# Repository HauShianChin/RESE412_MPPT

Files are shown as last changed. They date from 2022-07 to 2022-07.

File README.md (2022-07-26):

# RESE412_MPPT

MPPT PCB design in Simulink and Altium Designer 

## Final RESE412 assignment 1.pdf

This report, I explored the sizing of a nanogrid and a microgrid, performing a topology analysis. The analysis compares a community of individual nanogrids, with the more traditional method of microgrid design. Individual household power systems operating independently, versus a collective microgrid approach will be discussed.

When both the individual nanogrid and microgrid topologies are designed and simulated, I observed the losses within each topology to ascertain the efficiency of the systems. This information, along with the financial cost of the system will allow me to make a recommendation to a community as to which topology will be more economically viable in the long term.

## RESE412 assignment 2 demand side management.pdf

In report, I will be building on the previous assignment's model to improve the microgrid system with control. Additionally, I will be implementing demand side management (DSM) using a single thermostatically controlled load (water heater) in each house using Simulink. I will revisit the stand-alone PV/battery system and see if I can reduce the capital cost of the solution.

The aim is to shift the water heater load to a time that better suits PV power production. With this shift in load, I should be able to reduce your battery storage and in theory reduce the capital cost of the microgrid solution (ignoring the cost of control infrastructure). Another constraint is that the water reaches “T High WH” at least once a day (T High WH can be found in the Simulink model, ideally its 60 degrees, However, set a little lower in a couple of the houses). This is to ensure bacteria doesn’t build up in the water heater of the Simulink model.

## MPPT assignment 3 412 final and proofread.pdf

A maximum power point tracker (MPPT) is a device that you will see regularly in household renewable energy systems. It manages the output of the solar panels, typically incorporating a battery management system, sometimes even coupled with an inverter. The MPPT dynamically alters the impedance seen by the photovoltaic (PV) panels. This is particularly advantageous in cloudy conditions or if the load is changing regularly. In this project, I will be designing and building an MPPT that will connect to two 10W polycrystalline panels. Students will test their MPPT against a system which does not have any control in order to determine the success of the MPPT controller.

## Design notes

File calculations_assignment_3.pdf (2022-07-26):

close all
clc

Freq = 30000;
Vpp = 17.4;
Po = 21.228;
R1 = 1;
R2 = 10;
R3 = 100;

Iout1 = sqrt(Po/R1)

Iout1 = 4.6074
Vout1 = Iout1*R1

Vout1 = 4.6074
Pa = Iout1*Vout1

Pa = 21.2280

Iout2 = sqrt(Po/R2)

Iout2 = 1.4570
Vout2 = Iout2*R2

Vout2 = 14.5698
Pb = Iout2*Vout2

Pb = 21.2280

Iout3 = sqrt(Po/R3)

Iout3 = 0.4607
Vout3 = Iout3*R3

Vout3 = 46.0739
Pc = Iout3*Vout3

Pc = 21.2280

DL1 = 0.2*Iout1*(Vout1/Vpp)

DL1 = 0.2440
DL2 = 0.2*Iout2*(Vout2/Vpp)

DL2 = 0.2440

DL3 = 0.2*Iout3*(Vout3/Vpp)

DL3 = 0.2440

L1 = abs((Vpp*(Vout1-Vpp))/(Freq*DL1*Vout1))

L1 = 0.0066
L2 = abs((Vpp*(Vout2-Vpp))/(Freq*DL2*Vout2))

L2 = 4.6174e-04
L3 = abs((Vpp*(Vout3-Vpp))/(Freq*DL3*Vout3))

L3 = 0.0015

D1 = Vout1/(Vout1+Vpp)

D1 = 0.2094
D2 = Vout2/(Vout2+Vpp)

D2 = 0.4557
D3 = Vout3/(Vout3+Vpp)

D3 = 0.7259

C1 = (Iout1*D1)/(30000*0.05*Vout1)

C1 = 1.3957e-04
C2 = (Iout2*D2)/(30000*0.05*Vout2)

C2 = 3.0382e-05
C3 = (Iout3*D3)/(30000*0.05*Vout3)

C3 = 4.8391e-06

%current sensor
VoMax = 5 %voltage going into the MCU

VoMax = 5
VoMin = VoMax/(2^10) %min voltage going into the MCU

VoMin = 0.0049
Iimin = 0 %min current

Iimin = 0

ViMax = 50*10^-3 %at least 10x bigger than Vos

ViMax = 0.0500
IiMax = 0.61*2 % maximum current measured

IiMax = 1.2200

Rshunt = ViMax/IiMax %shunt resistor

Rshunt = 0.0410
G = (VoMax - VoMin)/((IiMax - Iimin)*Rshunt) %gain calculations

G = 99.9023
RpositiveIn = 1000 %positive terminal resistor

RpositiveIn = 1000
RpositiveFed = RpositiveIn*G %positive feedback

RpositiveFed = 9.9902e+04

%G = R3/R2

RnegativeIn = RpositiveIn

RnegativeIn = 1000
RnegativeFed = RpositiveFed

RnegativeFed = 9.9902e+04

%voltage sensor
%G = R2/R1 = 1/5
%VoMax voltage going into the MCU %VoMin min voltage going into the MCU %Gain = Vo/Vi
GVoltage = 5/17.4

GVoltage = 0.2874
RVoltageIn = 10000 %ohms

RVoltageIn = 10000
RVoltageFed = GVoltage*RVoltageIn

RVoltageFed = 2.8736e+03

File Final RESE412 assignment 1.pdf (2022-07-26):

Author: Hau Shian Chin
Student ID: 300493343
Introduction

The purpose of this report is to explore the idea of placing a microgrid and nanogrid system to support a community in Hicks Bay. This nano- and microgrid system's specifications include an analysis of the local environment, total load curve, and size of the nano- and microgrid. Additionally, the system must be off-grid and must service 95% of its load. We will analyse the cost and efficiency of both systems as well as their advantages and disadvantages to make a viable recommendation about load use and demand side management for this community.

Village Load and Resources Assessment

Hicks bay was picked as the subject of village load as it has both sufficient sun exposure as well as high wind currents due to being close to the sea. Furthermore, the exact location at which data will be collected from will be the coordinate of -37.595915, 178.300842. This would mean that the sunlight data and the wind data will be extracted from this location. Although not every solar panel and wind turbine can fit into this coordinate, this can be negligible when calculating the power provided to the village.

Topology

As the sun rises from the east and sets in the west, we would expect the location to not receive much sunlight before noon as it’s stationed next to 2 hills [1]. Additionally, this may result in a potential shade for the solar panels leading to less power output. This can be observed in Figure 1. However, peak sunlight hours calculated from NIWA may prove these 2 variables to be negligible. Furthermore, there may be some anomalies regarding how wind would be harvested. This may be negligible as well since both wind frequency and wind speed will be considered when calculating the harvestable wind in that region.

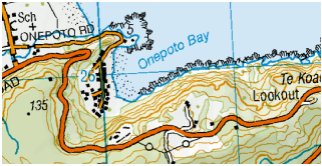
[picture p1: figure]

Figure 1: topology of the coordinate.

Resource assessment

Solar analysis

On NIWA the location was exposed to 3.107 hours of peak sunlight hours during the winter month (June) on average [2]. As winter has the least amount of sunlight hours of all seasons, it will tell us what is the least amount of energy we can harvest from the sun. Additionally, this will provide us with the sufficient data to model an energy supply from solar power. As shown in Figure 2, peak sunlight hours was calculated from the total sunlight hour, summed up to provide a total number of hours providing 1kW. This makes sense as the sun would peak at noon but set in the evening.

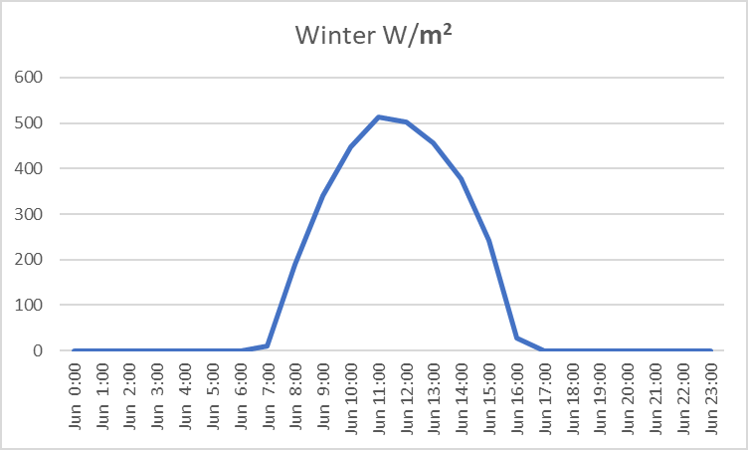
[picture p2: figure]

Figure 2: Mean sunlight hours during winter

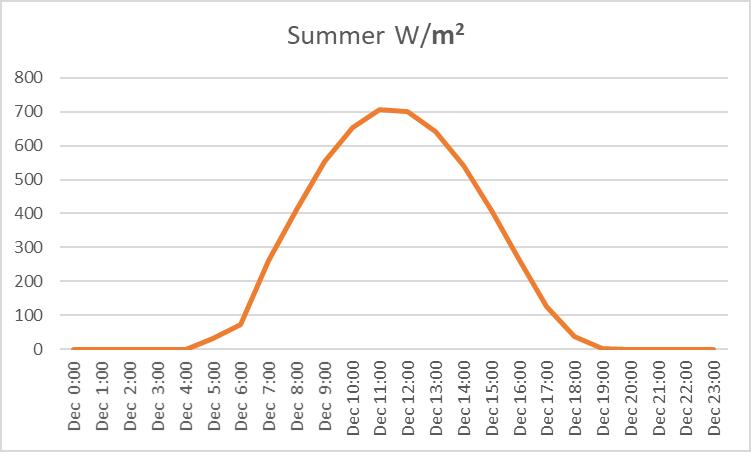
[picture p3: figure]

Figure 2: Mean sunlight hours during summer.

The Figure above is the sunlight hours during the summer month (December). This resulted in a peak sunlight hour of 5.417 hours during summer. Moreover, this may be considered as a constraint to determine the inverter power output when exporting power to the grid in the future. During the summer there may be network congestion due to other inverters exporting at the same time. However, this may be able to address future load growths during summer.

Wind analysis

Using the meteorology data of NIWA, we have compiled the first week of June's wind speed to determine the average effective wind hours [2]. The effective wind hours that are available in a single day is calculated by considering the wind speed, wind frequency at that speed and the curvature of the turbines to determine an energy output (Figure 3). This resulted in an effective wind hour of 4.475 hours a day.

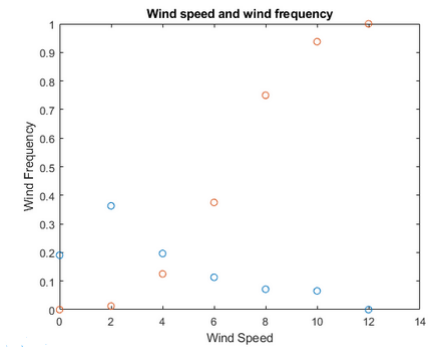
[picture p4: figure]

Figure 3: wind speed and wind frequency (e.g. 0.4 = 40% of the time) at that speed.

Load analysis

Nanogrid load analysis

To determine the load, a nanogrid will be considered as a single house’s load whereas a microgrid will be the load sum of 4 houses. Both winter and summer loads will be explored to provide a feasible comparison between the 2 seasons. Additionally, both loads and instantaneous power will be observed.

To calculate the energy expenditure of a single nanogrid. The current draw of each unit will be calculated and multiplied by the national rated voltage (240 V). These sets of discrete values will be sampled for every minute of the day to provide a set of instantaneous power. Moreover, this dataset requires integrating to provide the load curve and thus the energy expenditure of the household. Both summer and winter load curves of all the nanogrids can be seen on Figure 4. Green being house 8, blue being house 3, black being house 9 and orange being house 4. The load will be serviced using AC current as a result an inverter is needed to support the nano-microgrid.

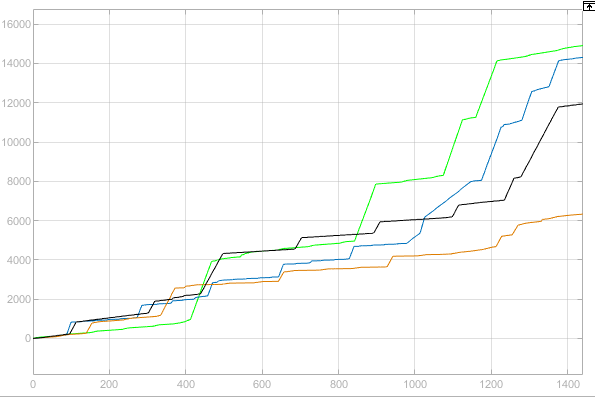
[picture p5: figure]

Summer load

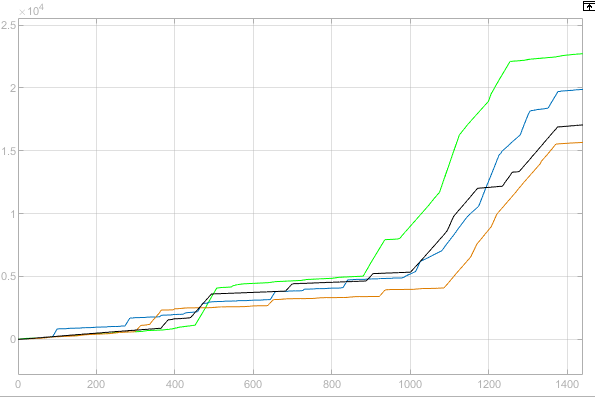
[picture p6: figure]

Winter load
Figure 4: Daily seasonal load curves of the nanogrids

The nanogrids’ energy expenditure for both summer and winter can be shown in Table 1, since the system has a minimum requirement of 95% of its load serviced, 100% of the energy expenditure will be considered as the excess that may be needed. These energy expenditures below will provide the sufficient energy required for component selection. It is expected that winter has higher energy demand than summer. As a result, all components selected for the nanogrid will be used to service its winter load. Additionally, the nanogrids energy expenditure can be totalled up to provide the energy expenditure for the microgrid. Instantaneous power determines the peak power drawn at any given time from the grid. This can be observed in Figure 5.1-4 where both summer and winter instantaneous power can be observed.

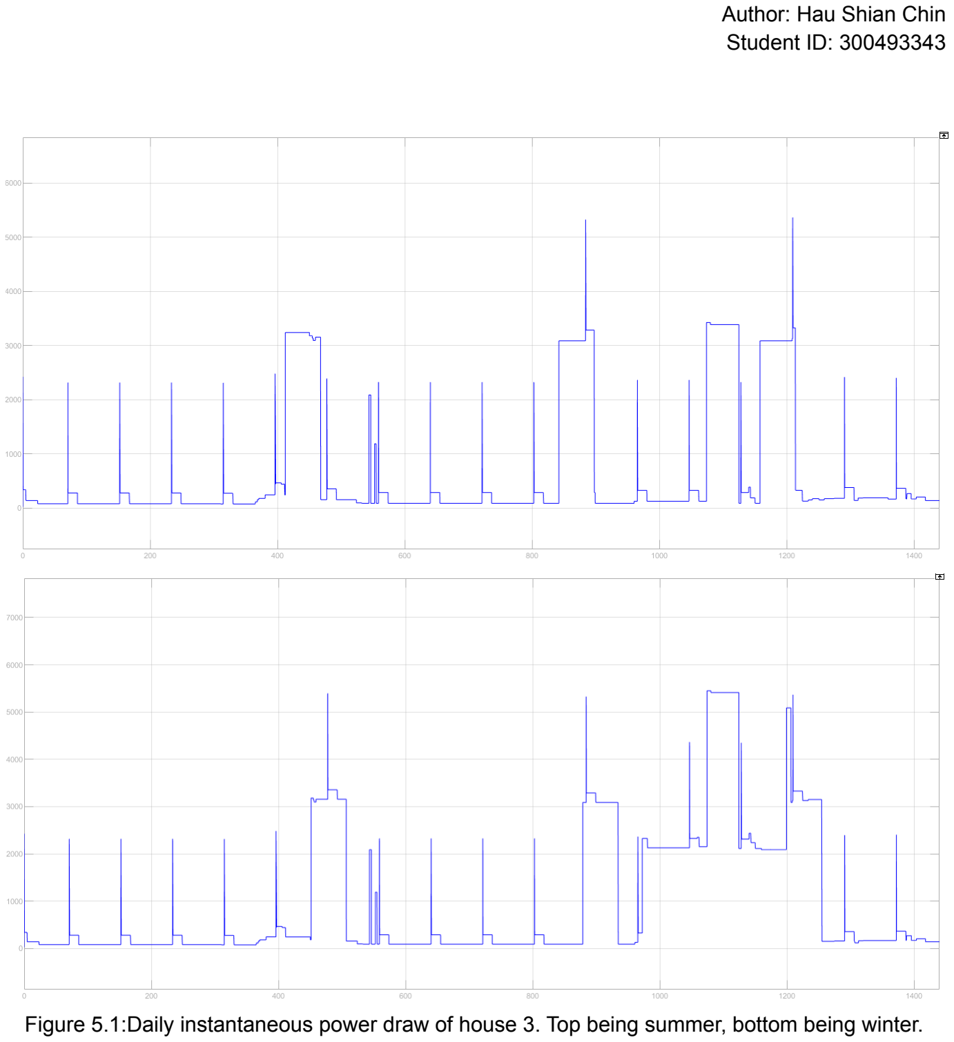
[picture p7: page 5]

Figure 5.1:Daily instantaneous power draw of house 3. Top being summer, bottom being winter.

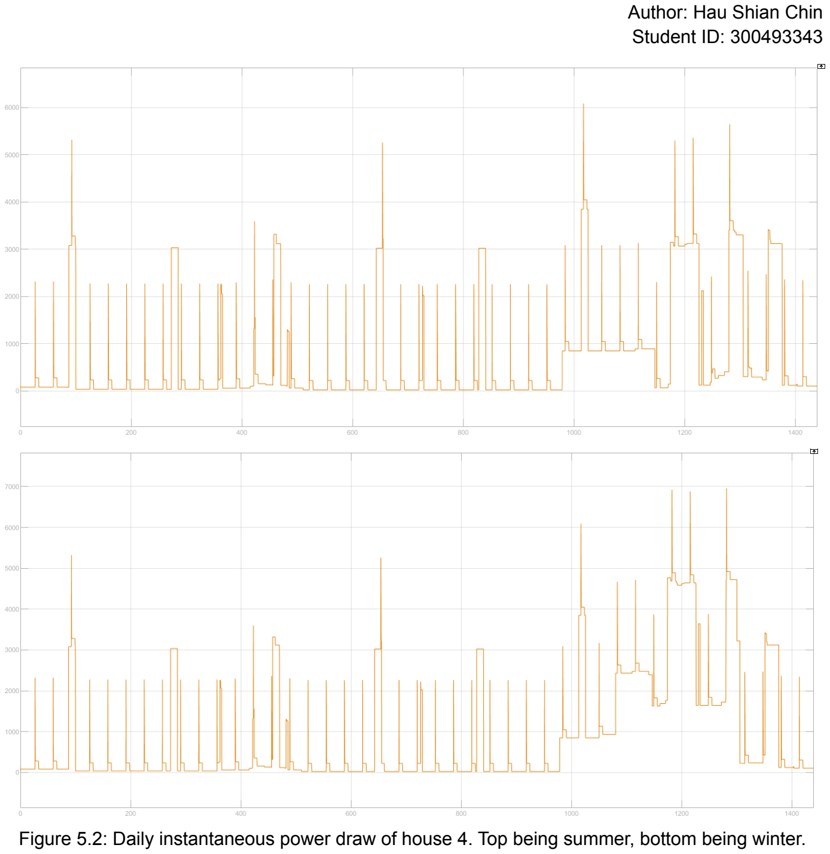
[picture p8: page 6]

Figure 5.2: Daily instantaneous power draw of house 4. Top being summer, bottom being winter.

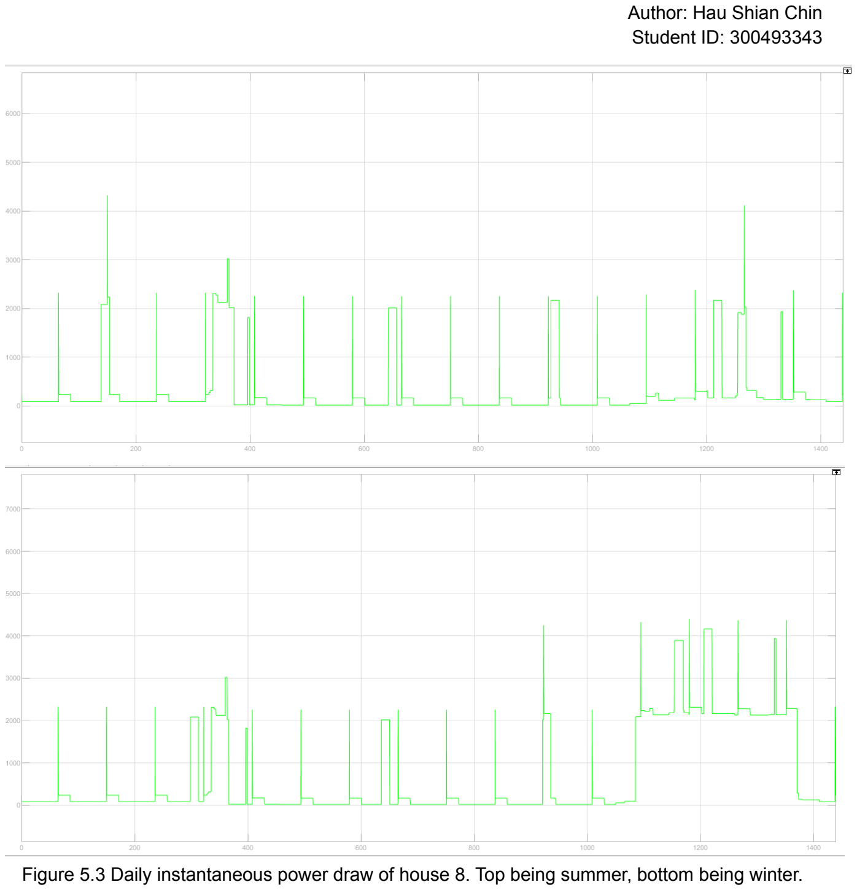
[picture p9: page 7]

Figure 5.3 Daily instantaneous power draw of house 8. Top being summer, bottom being winter.

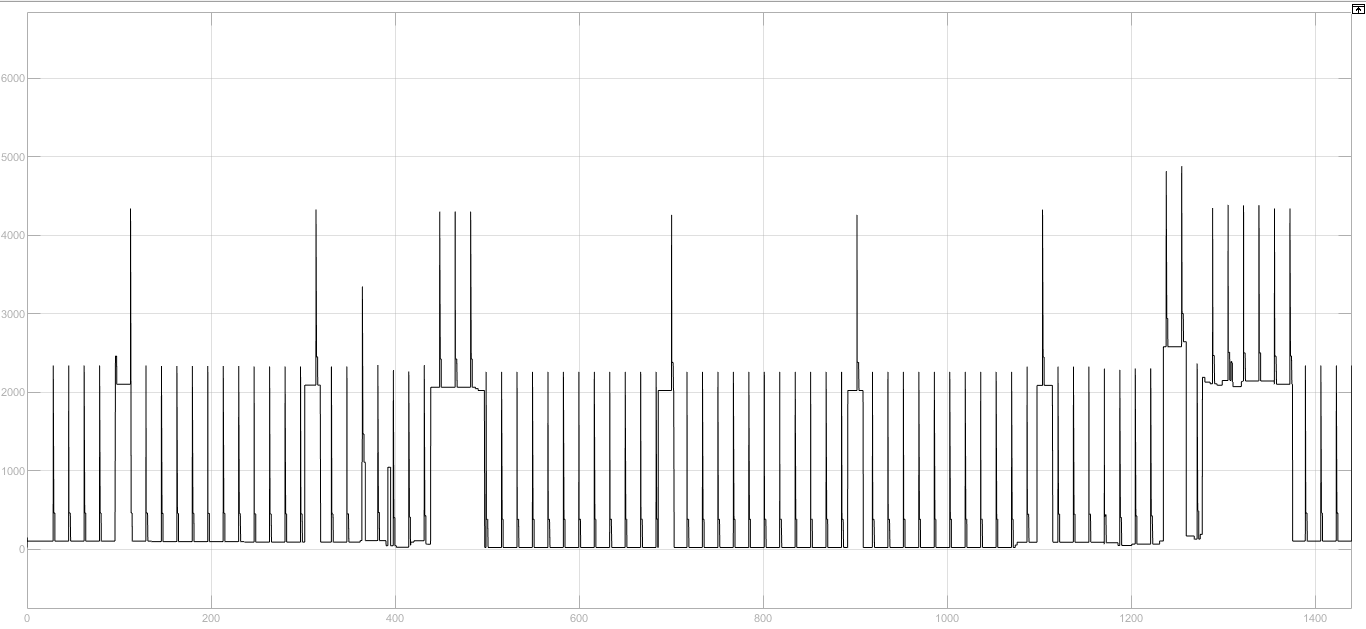
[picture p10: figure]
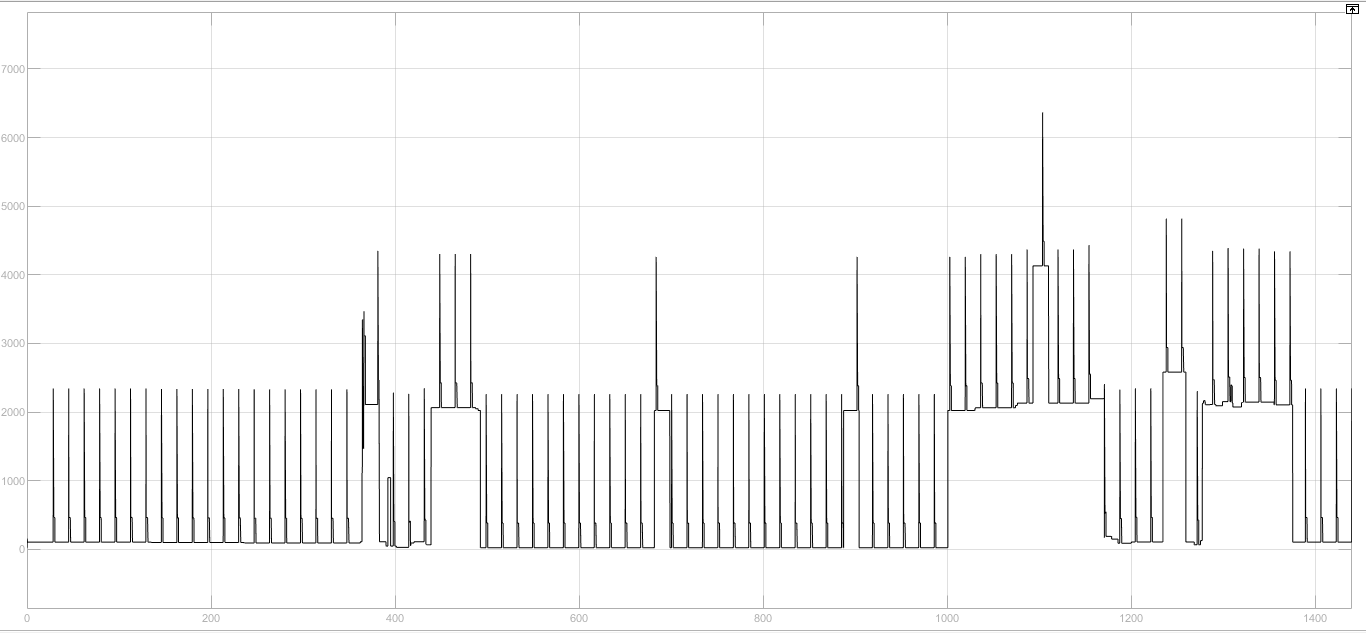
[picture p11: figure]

Figure 5.4: instantaneous power draw of house 9.Top being summer, bottom being winter.

These are the instantaneous power draw of each nanogrid. As shown in Figures 5.1-4, it is a recurring trait that all households tend to use more power during the evening. This makes sense as most people spend recreational time during the evening. E.g. watching TV, cooking. Unlike the daily energy expenditure the instantaneous power of each nanogrid is expected to be the same as most people would have the same routine year round.

Nanogrid | Summer daily energy expenditure | Peak instantaneous summer load | Winter daily energy expenditure | Peak instantaneous winter load
House 3 | 14.3 kWh | 6 kW | 19.8 kWh | 7 kW
House 4 | 6.4 kWh | 4.3 kW | 16.0 kWh | 4.5 kW
House 8 | 15.0 kWh | 5.4 kW | 23.2 kWh | 5.5 kW
House 9 | 12.0 kWh | 5 kW | 17.7 kWh | 5.4 kW
Table 1: seasonal energy expenditure of all nanogrids.

Microgrid load analysis

As shown in Figure 6.1, the summer microgrid daily energy expenditure is approximately 48 kWh. Whereas, the winter microgrid daily energy expenditure is approximately 77 kWh. As a result, winter energy expenditure will be considered when considering the capacity of battery, capacity of inverter, quantity of PVs and wind turbines selected.

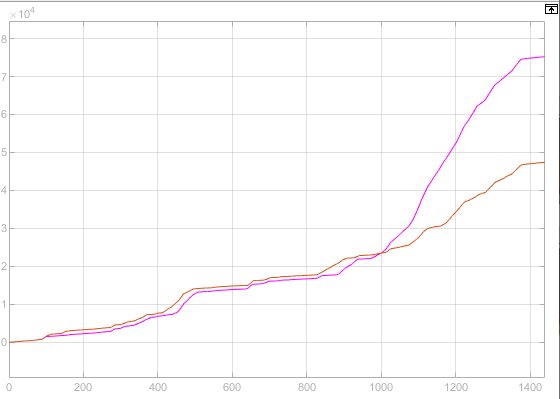
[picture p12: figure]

Figure 6.1: Microgrid daily energy expenditure for summer and winter. Purple = Winter, Orange = Summer

All wind turbines connected to the battery must first be converted to DC to allow the battery to charge. However, the PVs would not need any conversion to allow the battery to charge as its generated via DC current.

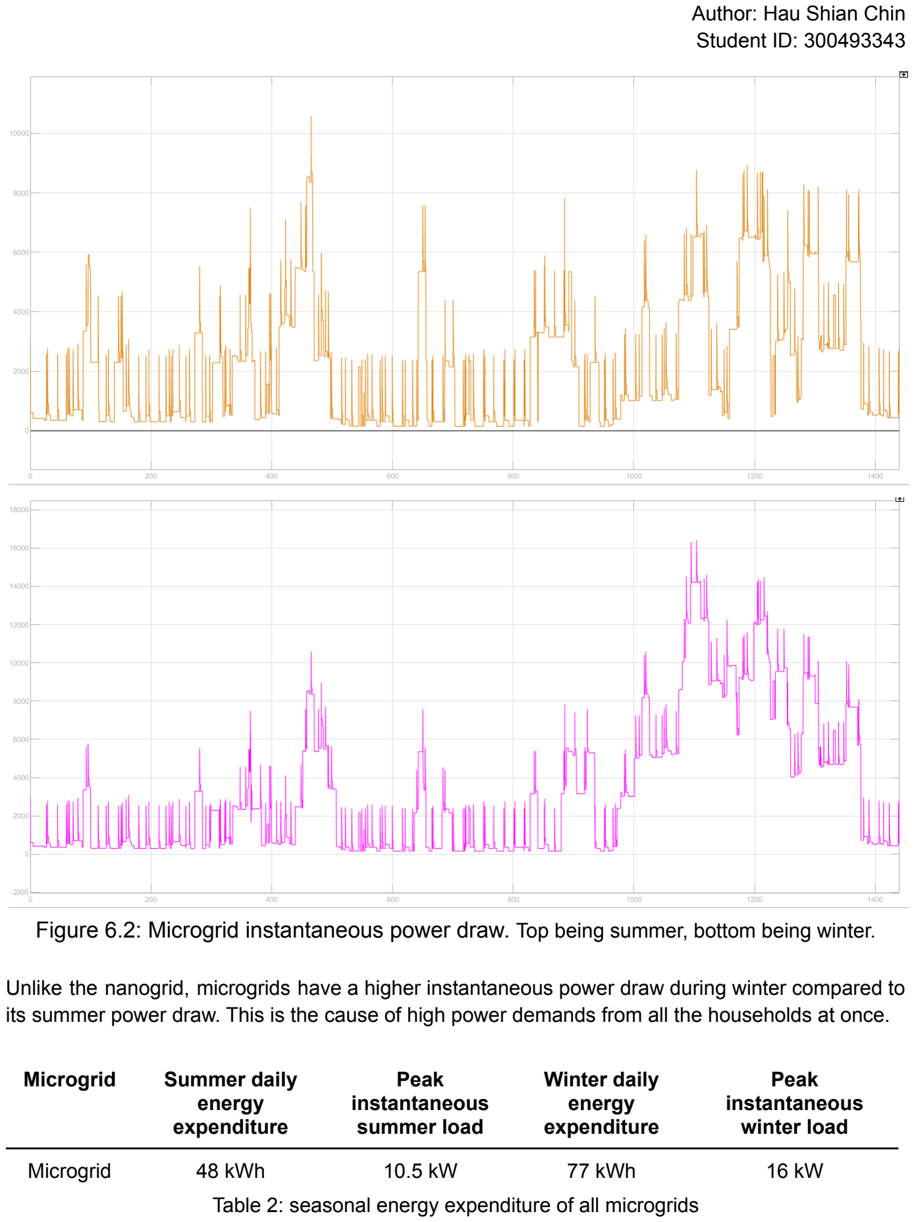
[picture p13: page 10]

Figure 6.2: Microgrid instantaneous power draw. Top being summer, bottom being winter.

Unlike the nanogrid, microgrids have a higher instantaneous power draw during winter compared to its summer power draw. This is the cause of high power demands from all the households at once.

Microgrid | Summer daily energy expenditure | Peak instantaneous summer load | Winter daily energy expenditure | Peak instantaneous winter load
Microgrid | 48 kWh | 10.5 kW | 77 kWh | 16 kW
Table 2: seasonal energy expenditure of all microgrids

Component Selection

component | Capital cost (per unit) | O&M cost | Replacement time
PV | $750 /kW | $1 /280W /year | 25 year
Wind | $1460 /kW | $146 / 500W /year | 20 year
Battery | $110 /kW | $11 /kWh /year | 10 year
Inverter | $364 /kW | 0.0026 /kW /year | 10 year
Table 3: component cost of the project in USD

PVs, wind turbines and battery selection will be based on the winter energy expenditure as it has a higher load curve compared to summer’s energy expenditure. Components selected from Table 3 must accommodate for the loads in Table 1. In addition, this allows us to compare the financial benefits of microgrid and nanogrid when their loads are high. For a self-sustaining community, it is more important to have an energy surplus than a deficit since to accommodate for later use. As a result, both solar panels and wind turbines calculated in Table 4 must be rounded up to ensure an energy surplus. Additionally, all calculations below will be done in USD before converting to NZD.

Method of energy harvesting

The method of energy harvesting will determine how the nanogrid will be powered. The method of harvesting would be PVs (solar energy) and/or wind turbines. To determine how many PVs and turbines required, the daily energy expenditure will be divided by the energy output of the system. Additionally, the initial cost will consider the required quantity of PVs and wind turbines, the rated power output and the initial cost of the equipment. Finally, the operation and maintenance cost (O&M cost) will consider the quantity of equipment and the annual operation and maintenance cost.

required quantity of equipment = Daily energy expenditure ፥ (power output * functional ℎours) initial cost = power output of tℎe equipment * required quantity of equipment * cost of equipment OM cost = O&M cost per year for tℎe equipment * required quantity of equipment

Nanogrid | Daily energy expenditure | Required PVs (280 W) | Initial cost | O&M cost per year
House 3 | 19.8 kWh | 23 | $4830 | $23
House 4 | 16.0 kWh | 19 | $3990 | $19
House 8 | 23.2 kWh | 27 | $5670 | $27
House 9 | 17.7 kWh | 21 | $4410 | $21

Nanogrid | Daily energy expenditure | Required wind turbines (500 W) | Initial cost | O&M cost per year
House 3 | 19.8 kWh | 9 | $6570 | $1314
House 4 | 16.0 kWh | 8 | $5840 | $1168
House 8 | 23.2 kWh | 11 | $8030 | $1606
House 9 | 17.7 kWh | 8 | $5840 | $1168
Table 4: PVs and wind turbines required quantity and costs for nanogrids

As shown in Table 4, although solar panels may be more cost effective in general. Solar panels are made redundant if there’s low sun exposure as well as only effective for 3.107 hours of the day. However, this can be made negligible by allowing a greater battery capacity. Wind turbines have a high upkeep cost and initial cost as a result, will not be considered when sizing the nanogrid. Additionally, it may require a voltage rectifier to charge the battery as the battery charges in DC.

Battery management system

Battery management system must be able to supply enough energy to the nanogrids until the next morning. Additionally, the battery management system must be doubled to accommodate for the days when power can not be generated as well as supporting the nanogrid during down time. This will lower the chances that the battery will go below 50% on cloudiest days during winter which may result in battery damage.

Nanogrid | Daily energy expenditure | Battery capacity | Initial cost | O&M cost per year | After replacement cost
House 3 | 19.8 kWh | 39.6 kWh | $4356 | $435.60 | $8712
House 4 | 16.0 kWh | 32 kWh | $3520 | $352 | $7040
House 8 | 23.2 kWh | 46.4 kWh | $5104 | $510.4 | $10208
House 9 | 17.7 kWh | 35.4 kWh | $3894 | $389.4 | $7788
Table 5: Battery capacity and costs for nanogrids

The cost stated in Table 5 was doubled to compensate for the replacement cost. This was the result of the battery lifespan being 10 years where this project span is 20 years.

Inverters

The purpose of the inverter is to provide sufficient AC power to the nanogrid. This AC power must accommodate for the peak instantaneous load as that’s the maximum load required to accommodate at any time. There must be extra capacity to prevent overloading. To accommodate for this safety measure, the inverter capacity will be 50% greater than the peak instantaneous power of the nanogrid when determining inverter capacity.

Nanogrid | Peak instantaneous power in winter (kW) | Inverter capacity | Initial cost | OM cost per year | After replacement cost
House 3 | 7 kW | 10.5 kW | $3,822 | $0.03 | $7,644
House 4 | 4.5 kW | 6.75 kW | $2,457 | $0.02 | $4,914
House 8 | 5.5 kW | 8.25 kW | $3,003 | $0.03 | $6,006
House 9 | 5.4 kW | 8.1 kW | $2,948.4 | $0.03 | $5,897
Table 6: Inverter capacity and costs for nanogrids

The cost stated in Table 6 was doubled to compensate for the replacement cost. This was the result of the inverter lifespan being 10 years where this project span is 20 years. There were some abnormalities since house 9 has a greater peak instantaneous power compared to house 4, this was a result of high power draw at a given time.

Nanogrid costs in NZD

Nanogrid | PVs cost + annual O&M cost | Wind turbines cost + annual O&M cost | Inverter cost + annual O&M cost | Battery cost + annual O&M cost
House 3 | $6,955 + $33 | $9,461 + $1,892 | $11,007 + $0.04 | $12,545 + $627.26
House 4 | $5,746 + $27 | $8,410 + $1,682 | $7,076 + $0.03 | $10,138 + $507
House 8 | $8,165 + $39 | $11,563 + $2,313 | $8,649 + $0.04 | $14,700 + $734.98
House 9 | $6,350 + $30 | $8,410 + $1,682 | $8,492 + $0.04 | $11,215 + $560.74
Table 7: Total cost of the components for nanogrids

Table 7 summarises the cost of each component from Tables 4 to 6 with its annual operating and maintenance cost in NZD (appended with an + sign). This will provide a better insight to the total cost of the nanogrid projects as the system is hosted in the NZ setting. As the initial and upkeep cost of wind is less cost effective than solar, wind power will not be used when sizing a nanogrid. However, it will be included in the economic analysis to provide an economical comparison.

Microgrid costs

All the calculations in Table 8 were done in USD to prevent miscalculations. As the energy expenditure of each nanogrid totals up to provide the microgrid’s energy expenditure, the total cost of PVs/wind and battery in the nanogrids can be totalled up to provide its respective cost for the microgrid.
Microgrid | Daily energy expenditure | Required PVs (280 W) | Initial cost | OM cost per year
Microgrid | 77 kWh | 90 | $18900 | $90
Microgrid | Daily energy expenditure | Required wind turbines (500 W) | Initial cost | OM cost per year
Microgrid | 77 kWh | 36 | $26,280 | $5256
Microgrid | Daily energy expenditure | Required battery capacity | Initial cost | OM cost per year | After replacement cost
Microgrid | 77 kWh | 153.4 kWh | $16,874 | $1,687 | $33,748
Microgrid | Peak instantaneous power in winter (kW) | Inverter capacity | Initial cost | OM cost per year | After replacement cost
Microgrid | 16 kW | 24 kW | $8,736 | $0.06 | $17,472
Table 8: Inverter capacity and costs for nanogrids

As shown in Table 2. The peak instantaneous power drawn for the microgrid is 16 kW. This allows the microgrid to cut costs for the inverter as it only requires 24 kW instead of the sum of the peak power drawn for the nanogrids.

Microgrid cost in NZD

Microgrid | PVs cost + annual O&M cost | Wind turbines cost + annual O&M cost | Inverter cost + annual O&M cost | Battery cost + annual O&M cost
Microgrid | $27,216 + $130 | $37,843 + $7,569 | $25,159.68 + $0.09 | $48,597 + $2,429.86
Table 9: Total cost of the components for nanogrids

Table 9 summarises the cost of the components in Table 8 along with its annual operating and maintenance cost in NZD (appended with an + sign). This will provide a better insight to the total cost of the microgrid project. As the initial and upkeep cost of wind is less cost effective than solar, wind power will not be used when sizing a microgrid. However, it will be included in the economic analysis to provide an economical comparison.

Nanogrid technical considerations

Technical considerations include making sure that all the inductive and capacitive loads have phase correction units so that it may not cause disturbance elsewhere in the house. In the nanogrid, software may be needed to optimise power usage, such as allowing charging to happen simultaneously with discharging. During the summer, when the PVs are more efficient, bus load may be a concern. It may be recommended that PVs operate during some of the daytime hours to avoid bus overload. All buses must be low resistance to prevent voltage curtailing.

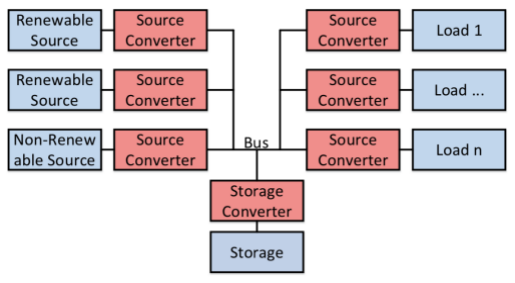
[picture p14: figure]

Figure 7: example of a bus load

Microgrid technical considerations

Microgrids will likely use more wiring and buses than the nanogrids. Additionally, the microgrid may need some protective brakes/relays to prevent any faults from affecting other houses. Furthermore, there may be an increase in bus load as the microgrid connects to each household thus, additional phase protection may need to be implemented to accommodate load growth. Single phase lines will be required to deliver power to each of the houses.

Microgrids will also require a more complex software to optimise the load demands of each household. This software may be used inside the central processing unit of the microgrid to accommodate for the load curves and bus load of the system. Furthermore, there will be additional costs associated with this software.

Nanogrid PVs system simulation model

To provide a realistic simulation of the nanogrids in simulink a week of tilted solar irradiance was picked. The week of the winter solstice was picked to provide the sunlight hours 21st of June 2021 to 27th of June 2021 [2]. This week was to showcase how the nanogrids would perform in the least optimal winter conditions. This week has a mean of 4.031 peak hours a week. As shown in the Figures below the nanogrids required to draw some energy out of the energy reserve to sustain the house. This was a result of a lack of solar irradiance during the day. The orange line represents the energy usage of the battery management system and the blue line represents the instantaneous power throughout the day. It can be observed in Figures 8.1-4 that all nanogrids have shown to be able to sustain the load demand of its household with a slight drop below 50% battery capacity. We can conclude that the components selected for the nanogrids are viable.

House 3

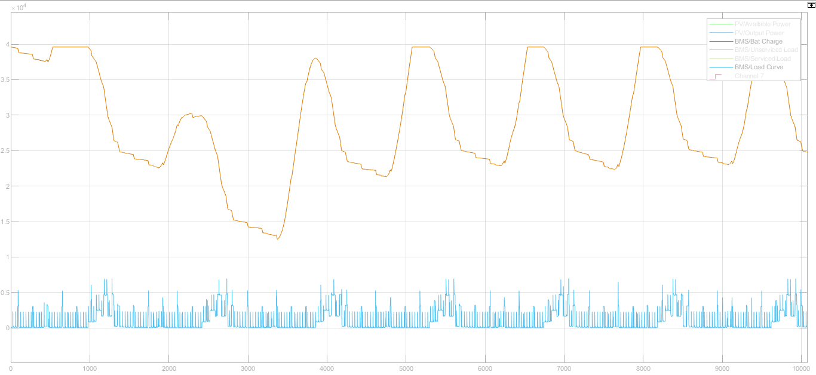
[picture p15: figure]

PVs capacity | Battery capacity | Inverter capacity
6.44 kW | 39.6 kWh | 10.5 kWh
Figure 8.1: house 3 battery management system and instantaneous power demand

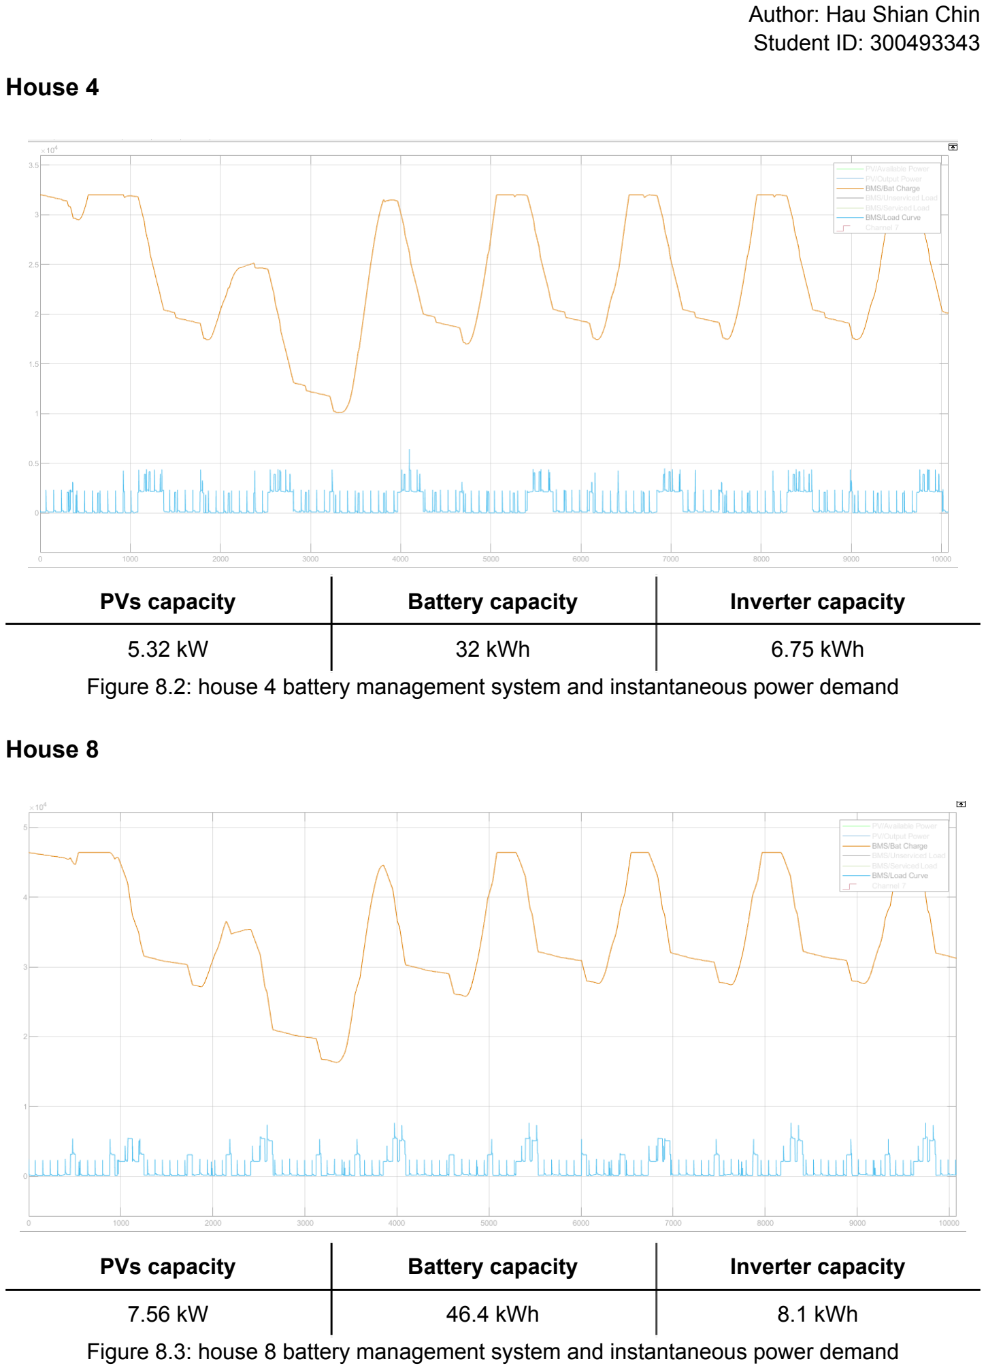
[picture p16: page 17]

House 4

PVs capacity | Battery capacity | Inverter capacity
5.32 kW | 32 kWh | 6.75 kWh
Figure 8.2: house 4 battery management system and instantaneous power demand

House 8

PVs capacity | Battery capacity | Inverter capacity
7.56 kW | 46.4 kWh | 8.1 kWh
Figure 8.3: house 8 battery management system and instantaneous power demand

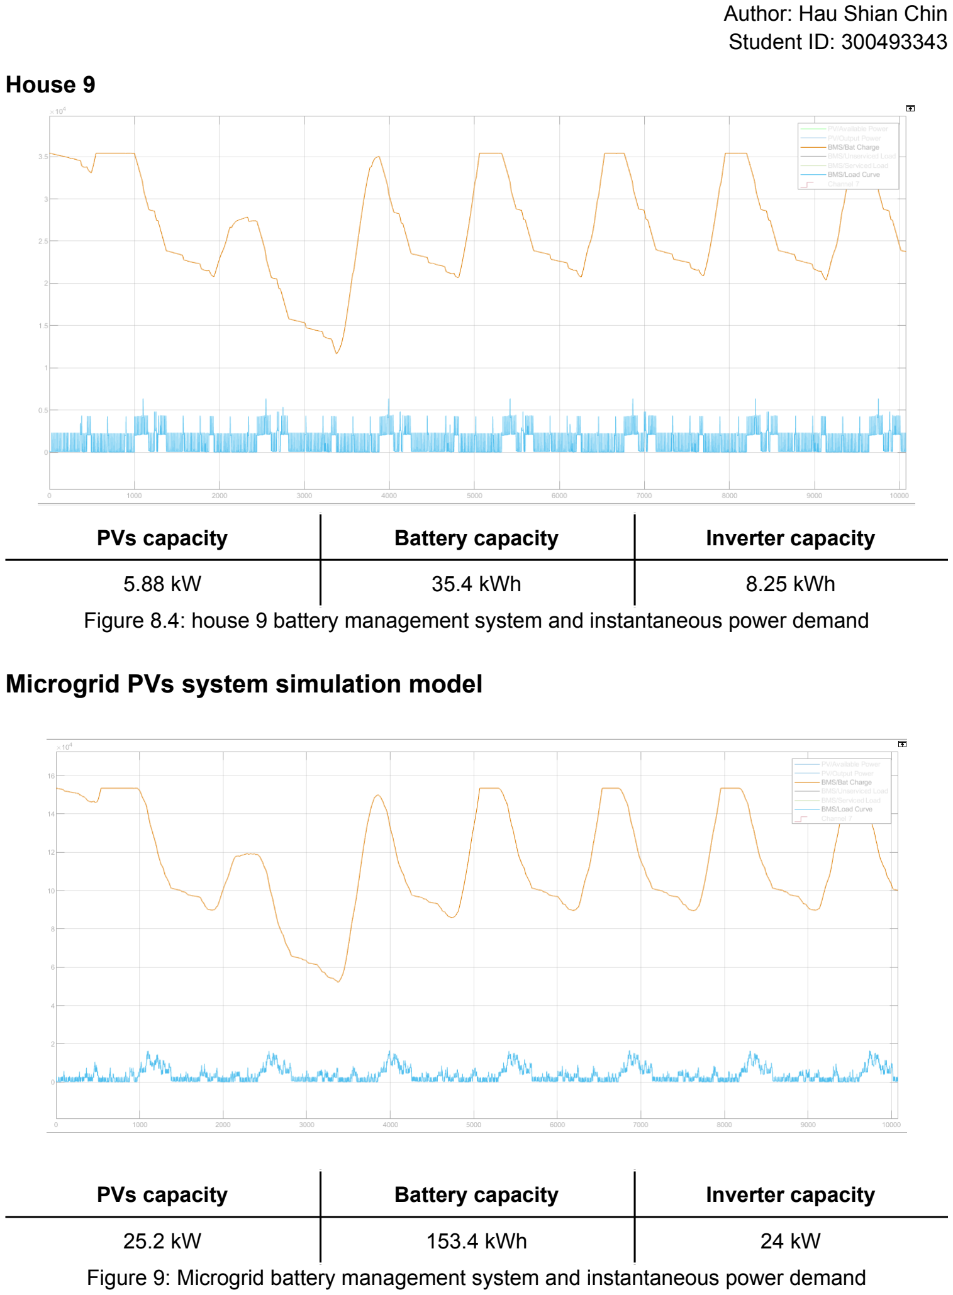
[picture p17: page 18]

House 9

PVs capacity | Battery capacity | Inverter capacity
5.88 kW | 35.4 kWh | 8.25 kWh
Figure 8.4: house 9 battery management system and instantaneous power demand

Microgrid PVs system simulation model

PVs capacity | Battery capacity | Inverter capacity
25.2 kW | 153.4 kWh | 24 kW
Figure 9: Microgrid battery management system and instantaneous power demand

The same process of exposing the microgrid with the same sunlight hours as the nanogrid provided a fair comparison of how each system would fare in the same weather conditions. In Figure 9, the orange line represents the energy usage of the battery and the blue line represents the instantaneous power drawn for the system. It can be observed that the battery was enough to sustain the load demand of the microgrid. As a result we conclude that the component selected would make this microgrid viable.

Nanogrid economical analysis

To determine the economical feasibility of the nanogrids, Simple Payback, Net Present Value and Levelised Cost of Energy (LCOE) will be used as a metric of comparison. The grid price per kwh ($0.29 NZD to $0.2 USD) will also be considered as well as rebates to determine the Simple Payback. Additionally, the PVs based system will only consider the cost of the battery, inverter and PVs whereas the wind based system will only consider the cost of the battery, inverter and PVs. The calculations will all be conducted in USD before converting to NZD to prevent miscalculations. NZD to USD conversion is assumed at $1.44 NZD to $1 USD.

Net Annual energy saving ($/year) = [AOE (kWℎ/year) * Price ($/kWℎ)] − O&M ($/year)

Nanogrid | Annual energy output (AOE) | PVs Net Annual Energy Savings (NZD) | Wind Net Annual Energy Savings (NZD)
House 3 | 7227 kWh | $ 1,420.95 | -$ 438.09
House 4 | 5840 kWh | $ 1,147.65 | -$ 506.91
House 8 | 8468 kWh | $ 1,664.90 | -$ 608.86
House 9 | 6460.5 kWh | $ 1,269.62 | -$ 382.06
Table 10: Annual energy output and Net Annual Energy Savings of PVs and wind nanogrids

As each nanogrid will not be using all its produced power throughout the year. The annual energy output (AOE) can be considered using the energy production during winter multiplied by the number of days in the year. As observed in Table 10 the Net Annual Energy Savings is higher for PVs.

Simple Paybacks

To calculate the Simple Paybacks (years) the total installed cost is calculated by summing the cost of the PVs/wind turbines, battery cost and inverter cost. This payback will provide an insight as to when the cost of the project would break even. As observed in Table 11, PVs can break even during the span of the project but not wind turbines.
Paybacks (year) =

installed cost($) −Rebates($) Net Annual Energy Savings ($/year)
Nanogrid | PVs Simple Payback (years) | Wind turbines Simple Payback (years)
House 3 | 20.1 | 70.8
House 4 | 18.3 | 46.6
House 8 | 17.7 | 54.1
House 9 | 18.9 | 68.4
Table 11: Simple Payback for PVs and wind nanogrids

Discounted Net Annual Savings

Using Figure 10, we select a discount rate of 2% as well as consider the project span of 20 years. This provided a PVAF of 16.35. This can be used to calculate the Discounted Net Annual Savings in the Table below. The Net Present Value will consider all costs and savings for the lifetime of the project. Furthermore, the Net Present Value (NPV) can be calculated by subtracting the Discounted Net Annual Savings from the Initial Cost and the Rebates. Rebates are used as part of the initial cost as the government issues out financial incentives for the construction of nanogrids ($1389 USD).

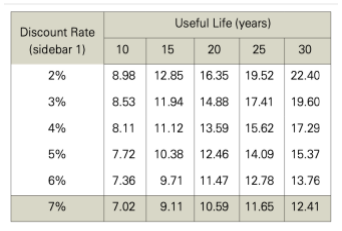
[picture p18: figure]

Figure 10: PVAF

Discounted Net Annual Savings ($) = Net Annual Energy Savings ($/year) * PVAF
Net Present Value (NPV) ($) = Discounted Net Annual Savings ($) − (installed cost($) − Rebates($))
Nanogrid | PVs Discounted Net Annual Savings (NZD) | Wind turbines Discounted Net Annual Savings (NZD) | PVs Net Present Value (NPV) (NZD) | Wind Net Present Value (NPV) (NZD)
House 3 | $ 23,232.57 | -$7,162.73 | -$5,275.11 | -$38,176.01
House 4 | $ 18,764.15 | -$8,287.91 | -$2,209.45 | -$31,911.11
House 8 | $ 27,221.07 | -$9,954.91 | -$2,291.73 | -$42,866.11
House 9 | $ 20,758.25 | -$6,246.72 | -$3,298.10 | -$32,362.27
Table 12: Discounted Net Annual Savings and Net Present Value of PVs and wind turbines for nanogrids

As observed in Table 12 all the NPVs for all nanogrids are negative, the nanogrid project will most likely lose money. As a result, this system is not economically viable. However, if a system must be built, the most economically viable ones would be the PVs as it has the highest NPVs values, specifically house 4 as it has the highest Discounted Net Annual Savings and NPV.

Levelised Cost of Energy

The Levelised Cost of Energy (LCOE) represents the discounted price that the system provides to breakeven over the project lifespan [3]. The nanogrids would be economically feasible if the LCOE is less than the grid price per kWh since it would be more cost effective to use the generated electricity than import power from the grid.

LCOE ($/kWℎ) =

Initial cost ($) + O&M ($/year) * PVAF Annual Energy Output (kWℎ/year) * PVAF

Nanogrid | PVs LCOE (NZD) | Wind turbines LCOE (NZD)
House 3 | $ 0.33 | $ 0.60
House 4 | $ 0.30 | $ 0.62
House 8 | $ 0.30 | $ 0.60
House 9 | $ 0.32 | $ 0.59
Table 13: LCOE of PVs / Wind nanogrids

As shown on the Table above, the LCOE is more than the price per kWh ($0.29) as a result not economically viable. However, there can be additional benefits such as being robust against outages. Outages can happen when there’s a sudden power demand in a more densely populated area and the grid will redirect power to accommodate the demand. Furthermore, the LCOE of the PVs system can be lowered there’s an increase in energy expenditure. This may indicate that an internal load growth may decrease the Levelised Cost of Energy.

Microgrid economical analysis

Using the same formulas and principles conducted on the nanogrids. We can obtain the Net Annual Energy Savings, Simple Paybacks, Net Present Value and Levelised Cost of Energy for the microgrid. These figures will help determine whether a microgrid project is economically viable.

Microgrid | Annual energy output (AOE) | PVs Net Annual Energy Savings (NZD) | Wind turbines Net Annual Energy Savings (NZD)
Microgrid | 28105 kWh | $ 5,590.90 | -$ 1,848.14
Table 14: Annual energy output and Net Annual Energy Savings of PVs and wind microgrid
Microgrid | PVs Simple Payback (years) | Wind Simple Payback (years)
Microgrid | 17.7 | 59.3
Table 15: Simple Payback for PVs and wind microgrid

Microgrid | PVs Discounted Net Annual Savings (NZD) | Wind Discounted Net Annual Savings (NZD) | PVs Net Present Value (NPV) (NZD) | Wind Net Present Value (NPV) (NZD)
Microgrid | $ 91,411.28 | -$ 30,217.02 | -$ 7,561.52 | -$ 139,817.02
Table 16: Discounted Net Annual Savings and Net Present Value of PVs and wind turbines for microgrid
Microgrid | PVs LCOE (NZD) | Wind turbines LCOE (NZD)
Microgrid | $ 0.31 | $ 0.59
Table 17: LCOE of PVs / Wind nanogrids for microgrid

In terms of NPV, Net Annual Energy Savings and Discounted Net Annual Savings, it has shown to be a similar value to the sum of the nanogrids as observed in Tables 14-17. However, the Simple Payback and LCOE indicates that the microgrid is slightly more economically viable than the nanogrid. This was a result of the lower cost spent on the inverter.

Conclusion and Recommendations

The location for this project may be improved to Whakatane as it’s a sunnier location. This would result in higher peak sunlight hours and require less PVs to support the microgrid. This would result in an overall lower cost to the project and would increase the Discounted Net Annual Savings of the project and decrease the LCOE. Additionally, an improvement in PV technology would also make microgrids more economically viable in the future. Furthemore, an Maximum Power Point Tracking (MPPT) could be implemented to maximise power output resulting in a more cost effective system.

We can also conclude that the PVs system was more economically feasible than the wind turbine. However, a hybrid system where both wind turbines and PVs are employed may be a viable solution. An example of the hybrid system would be the nanogrid on the Laby Building of Victoria University of Wellington [4].

Comparing the cost of having 4 nanogrid against the microgrid. The Microgrid has shown to be more economically viable due to the instantaneous power drawn. This resulted in lower cost spent in the inverter making it more cost effective. Having a microgrid system will lower the demand of fossil fuel used in NZ as a result will assist in reaching carbon emission goals.

The microgrid may be profitable if the inverter was connected to the grid for power export. There may be short term costs associated with power export; standard regulations (AS4777.2 2020) [5]. Furthemore, power export may come with additional tax if being sold back to the grid. To make the microgrid more profitable, the project must span longer than 20 years. There may be network congestion in the summer due to high energy output from PVs. This may be resolved if a dynamic export limiter was implemented to the microgrid [6].

Bibliography

[1] NZ Topo Map. n.d. New Zealand Topographic Map - NZ Topo Map. [online] Available at: <https://www.topomap.co.nz/NZTopoMap?v=2&ll=-37.596518,178.302183&z=15> [Accessed 8 April 2022].
[2] https://solarview.niwa.co.nz/. 2022. Custom location: -37.595915, 178.300842. [online] Available at: <https://solarview.niwa.co.nz/> [Accessed 8 April 2022].
[3] Durury, E., Denholm, P. and Margolis, R., 2011. The Impact of Different Economic Performance Metrics on the Perceived Value of Solar Photovoltaics. [online] Nrel.gov. Available at: <https://www.nrel.gov/docs/fy12osti/52197.pdf> [Accessed 8 April 2022].
[4] D. Burmester, R. Rayudu, and E. Massold, Setup of a Nanogrid for teaching purposes, ecs.wgtn.ac.nz. [Online]. Available: https://ecs.wgtn.ac.nz/foswiki/pub/Groups/PRES/ECSNanogrid/IEEETALE2014_(2).pdf. [Accessed: 08 Apr 2022].
[5] Standards.govt.nz. 2020. AS/NZS 4777.2:2020 :: Standards New Zealand. [online] Available at: <https://www.standards.govt.nz/shop/asnzs-4777-22020/> [Accessed 8 April 2022].
[6] Energex.com.au. n.d. DMIA Case Study Enabling Dynamic Export Limits for Commercial Solar PV. [online] Available at: <https://www.energex.com.au/__data/assets/pdf_file/0008/943487/DMIA-Case-Study-Cleveland-Sol ar-Dynamic-Operating-Envelope.pdf> [Accessed 8 April 2022].

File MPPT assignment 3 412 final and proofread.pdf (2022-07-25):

Abstract

With renewable energy based households becoming more energy efficient to maximise the output of renewable energy systems, a maximum power point tracker (MPPT) may be a recommended addition to the household’s battery management system. The purpose of this document is to explore the feasibility of an MPPT by creating an MPPT prototype using an incremental conductance algorithm and comparing the effectiveness of a photovoltaic system using an MPPT versus a photovoltaic system not using an MPPT.

Author: Hau Shian Chin
Student ID: 300493343

### 1. Introduction

To improve the power efficiency of any household renewable energy system, a maximum power point tracker (MPPT) should be incorporated into the battery management system (BMS), perhaps even coupled with an inverter. An MPPT dynamically alters the impedance of the photovoltaic (PV) panels to achieve maximum power output. MPPTs are incredibly beneficial in cloudy weather or if the load changes regularly.
To assess the efficacy of an MPPT inside the renewable energy system. A controlled PV system and an uncontrolled PV system be provided with the same step input solar irradiance. Both PV systems encompass two polycrystalline panels which will provide an output that can be used to compare the systems.

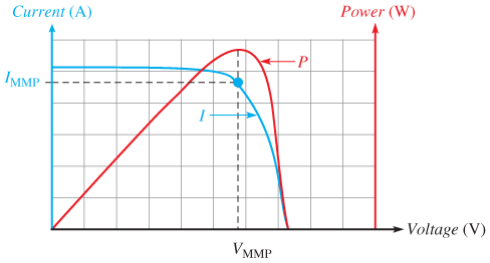
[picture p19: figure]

Figure 1: MPPT example [1]

An example can be observed in Figure 1, the impedance of the PV was manipulated to achieve the maximum power point (MPP), it increases or decreases the voltage and current accordingly so that it maintains the maximum power output from the PV system .

### 2. Background

### 2.1. Topology of the PV system

The configuration of the PV system which encompasses two polycrystalline panels is set to parallel so that in the event of a cloudy forecast, power may still be produced by the unshaded PV; as shown in Figure 2.1. As a result, the components selected for the MPPT must be able to tolerate higher current instead of voltages. This PV system will then be connected into an MPPT circuit to allow for maximum power output.

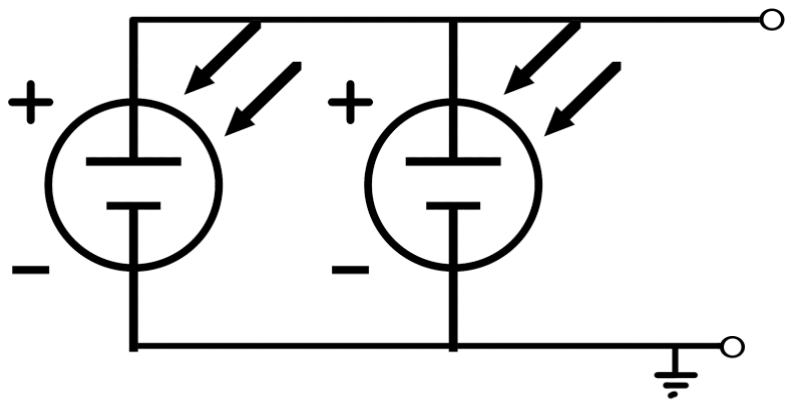
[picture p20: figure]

Figure 2.1: Example of parallel PV configuration

### 2.2. MPPT Algorithm

The complexity of an MPPT algorithm is limited to the processing capabilities of the microcontroller (MCU). Complex algorithms (genetic algorithms, fuzzy logic algorithms) tend to be more computationally intensive, thus more expensive MCUs are required to run these algorithms. Therefore, it can be justified that the MPPT uses a less computationally intensive algorithm such as “Perturb and Observe (P & O)” or “Incremental Conductance (InC)” to reduce the cost spent on the MCU.
Although the P & O algorithm is less complex, the InC algorithm allows for more dynamic performance during turbulent weather. Moreover, InC accurately finds the MPP in changing atmospheric conditions while P & O requires more stable weather conditions [2]. In the event that the renewable energy system household is located in a location with a turbulent climate, an InC algorithm-based algorithm will make the MPPT more globally viable. Additionally, P&O comes with higher oscillations at the MPP, which could prove to be hazardous and add to the wear and tear of the inverters / BMS.

### 2.3. Component parameters

### 2.3.1. Sensors

As both the P & O and InC algorithms require voltage and current inputs of the PV system. Voltage / current sensors are required. However, due to the budget constraints of this project, it is recommended to build a current sensor with a shunt resistor and a differential amplifier to detect the current supplied by the PV. Moreover, a voltage sensor can be built with a negative feedback operational amplifier (opAmp) to detect the voltage across the PV, this is more favourable than a voltage divider as there is less power being drawn from the PV. Resistors selected for these sensors must be of high value to prevent unnecessary current drain. The output of these amplifiers must fit within the resolution of the MCU’s analogue to digital converter (ADC). Additionally, the output of these opAmp cannot be greater than 5V as it would damage the MCUs.

### 2.3.2. Microcontroller (MCU)

Controlling the MPPT circuit to achieve MPP, a MCU is required as it can process the current and voltage observed by sensors to produce a duty cycle pulse associated with these sets of input. This duty cycle can then be accepted by the gate driver to control the MOSFET of the buck-boost converter that regulates the power input to the load, in a practical setting this load may be a BMS.

### 2.3.3. DC to DC converter

When connecting the PV power output to the power input of the BMS, DC to DC power conversion is required. Buck-boost converters such as the one shown in Figure 2.3.3, should be utilised when regulating the charging of the BMS. Using the output of an MCU, a gate driver can output a PWM that controls the switching frequency of a MOSFET of a buck-boost converter, thus regulating the required voltage input of the BMS. Using a buck-boost converter is recommended for an MPPT as it reduces power conversion loss on a wide voltage variation of the battery compared to using a variable voltage divider; which results in low power efficiency, or a buck / boost converter which can only decrease / increase the voltage respectively [3]. Furthermore, this is beneficial for resource dependent projects such as a renewable energy household due to its energy efficiency.

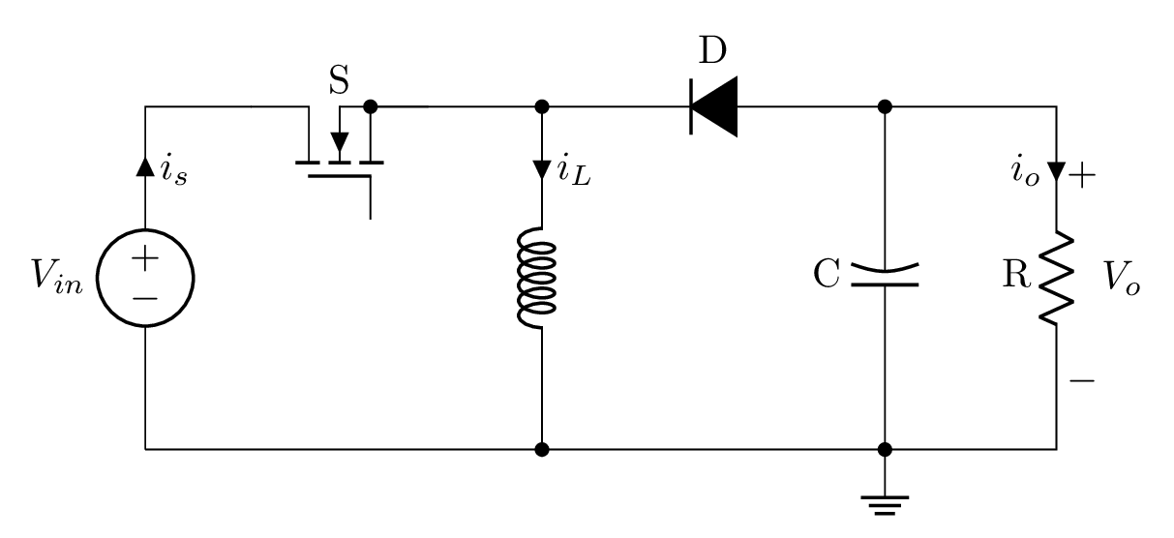
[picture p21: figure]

Figure 2.3.3: Buck-boost converter schematic [4]

### 2.4. MPPT arrangement

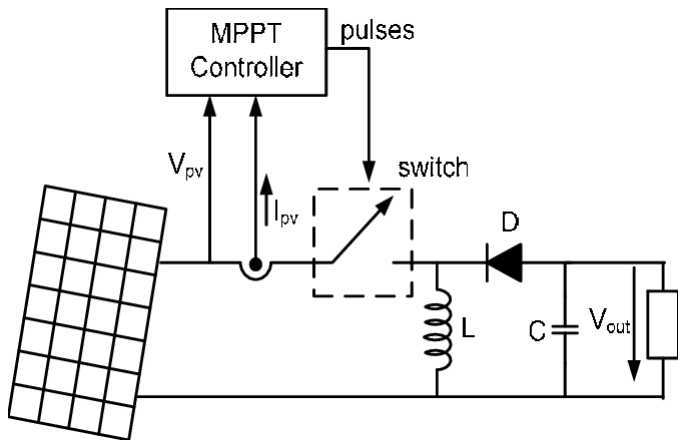
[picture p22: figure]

Figure 2.4: MPPT diagram [5]

Figure 2.4 shows how the MPPT will be arranged with the current PV system and the BMS. The BMS can be represented by the load resistors. The inductor, capacitor and the diode configuration along with the load resistor represented the buck-boost section of the MPPT whereas the switch, pulse and MPPT controller represented the MOSFET, gate driver output and the MCU respectively. Additionally, the Vpv and Ipv represent the current sensors that observe the voltage and current output of the PV system.
Voltage and current combinations that are inefficient can be detected by the sensors and corrected by the MPPT controller before power is applied to the BMS. The MPPT system is designed in such a way that the imperfections can be corrected to regulate power properly through the system by adjusting switching frequency.

### 3. Design

### 3.1. Component selection

Components selected for the MPPT considers the budget constraints ($50) and the component parameters mentioned in 2.3. Moreover, following Figure 2.4 provides the guidelines as to the required components. Additionally, components selected must tolerate a higher current due to the parallel arrangement of the PV system; A maximum voltage of 17.4 V and maximum current 1.22 A. Although the voltage is not the PV’s short circuit value, it can be made negligible as it is only relevant for the MOSFET rated voltage range.
Due to the time constraints of this project, the Arduino Uno was selected as the MCU which comes with a 10 bit ADC for the voltage and current sensors, thus a 4.9mV minimum input voltage. The load resistor of the MPPT which represents the BMS (in a practical scenario) will be 1Ω, 10Ω and 100Ω to determine the MPPT’s feasibility.
The gate driver and MOSFET selected for this project may be unideal, IR2117 and FPQ50N06 (gate driver and MOSFET respectively) was selected as it has been used in a previous buck-boost converter project. 4 and 2 pin terminals were selected for a way to connect the PV system, the MCU while simultaneously providing power to the sensors and gate driver.

### 3.1.1. Component value calculations

### 3.1.1.1. Sensors

Voltage sensors can be made with a negative feedback opAmp circuit. Calculating the gain of this opAmp while considering the maximum voltage of 17 V and the maximum input voltage of the Arduino MCU to be 5 V; will result in a gain of 0.29 as shown in Equation 3.1.1.1a. This means that at maximum output from the voltage sensor will be less than 5V to prevent hardware damage. Furthermore, high resistor values must be selected making R 10 kΩ and 2.9kΩ; an example can
i

R
f
be shown in Figure 3.1.1.1a. Due to the 10 bit ADC nature of the Arduino the minimum detectable voltage from the PV system would be 1.6mV.

17
5

−1
= 0. 29 .: G = 0. 29, G = −

R
f
R
1

=

2.9kΩ
10 kΩ
Equation 3.1.1.1a: Voltage sensor gain calculations

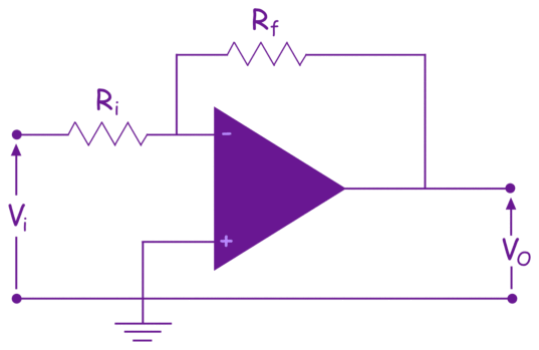
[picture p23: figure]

Figure 3.1.1.1a: Negative feedback opAmp example [6]

The shunt resistor provides an ease of current flow which can be used to calculate the current provided by the PV system via a differential opAmp. This will result in a voltage output that would reflect the current provided by the PV system. As the voltage applied onto the shunt resistor is small, the gain of the current sensor must be high to meet the minimum resolution of the 10 bit ADC.

Vomax = 5V, Vomin =

5
2

10 V, Iimin = 0, Vimax = 50mV, Iimax = 0. 61 * 2 A

R

sℎunt =

Vimax

Iimax

=

0.05
1.22 = 0. 041Ω, G =

Vomax−Vomin

(Iimax−Iimin

)*R
sℎunt

= 99. 9023

Equation 3.1.1.1b: Shunt resistor and differential opAmp gain calculations

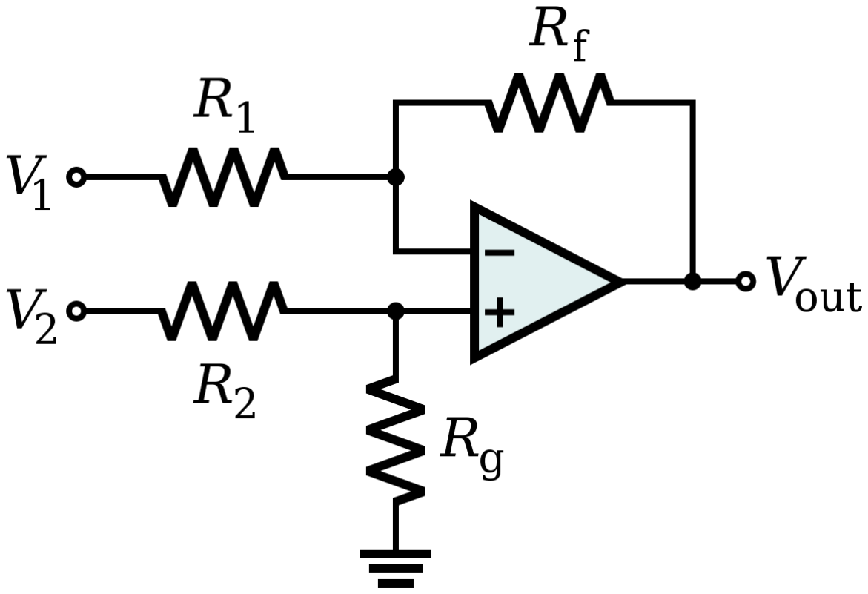
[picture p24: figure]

Figure 3.1.1.1b: Example of a differential opAmp [7]

The resistor values selected for differential opAmp can provided as R | ; as
1 = R
2

, R

f = R
g
shown in Figure 3.1.1.1b, thus to meet the provided gain parameters of the differential amp
R | as calculated in Equation 3.1.1.1b.
1 = R

2 = 1kΩ, R

f = R

g = 99. 9kΩ

### 3.1.1.2. Buck-boost converter

To calculate the capacitor and inductor values of the buck-boost converter, current output from the PV system with the respective 1Ω, 10Ω, 100Ω load resistors must be considered. This will provide voltage values for the buck-boost converter equations, thus the capacitor and inductor values for the buck-boost. Furthermore, as the current value varies depending on the load resistor, this will result in varying capacitor and inductor values for the varying load resistor. Rated voltage of the PV can be given as 17.4V and 0.61A. Additionally, the frequency output of MCU is clocked at 30kHz.

R = 1Ω, 10Ω, 100Ω, V

pp = 17. 4V, f = 30kHz

I

out =

P
out
R =

21.228
R = 4. 6074A, 1. 457A, 0. 4607A .: V =

P
out
I
out

= 4. 61V, 14. 6V, 46. 1V

∆L = 0. 2 * I
out

*

V
out
V
pp

= 0. 244, L = abs(

V
pp

*(V

out−V
pp

)

30*10

3
*(∆L*V
out

)

) = 6. 60mH, 0. 462mH, 1. 50mH

D =

V
out
V

out+V
pp

= 0. 2094, 0. 4557, 0. 7259, C =

I
out

*D

30*10

3
*0.05*V
out

= 0. 14mF, 0. 03mF, 4. 84µF

Equation 3.1.1.2: Calculating the capacitor and inductor values for the buck-boost converter

As shown in Equation 3.1.1.2, the capacitor and inductor value varies for different load resistor values. As only one inductor and capacitor value may be selected, it may be feasible to select the capacitor and inductor values for the 100Ω resistor. This will allow for greater resolution when observing the efficacy of the MPPT due to higher power draw.

### 3.1.2. Bill of Materials (BOM)

supplier | Manu. No. | Quantity | Description
Element14 | 12FR040E | 1 | 0.04Ω shunt resistor
Element14 | CGS553U030W4C | 1 | 55000uF smoothing cap
Element14 | ECA2AHG100 | 2 | 10uF capacitor
Element14 | FQP50N06 | 1 | N gate MOSFET
Element14 | UG1B-E3/54 | 2 | diode
Element14 | MCAP115018077-561LU | 1 | 560μH inductor,
Element14 | ECA1HHG221 | 1 | 220μF capacitor
Element14 | CTBP3051/2 | 1 | 2 pin terminal
Element14 | IR2117 | 1 | Gate driver
RS-pro | 897-1339 | 1 | 4 pin terminal

Table 3.1.2: Purchased BOM

As observed in table final BOM deviated from the calculated values of the buck-boost converter in Section 3.1.1.2 due to miscalculations that occured when designing the original buck-boost converter for the MPPT. This resulted in an incorrect inductor and capacitor values in the purchased BOM. Although the combination of the inductor and capacitor values may work, the MPPT may not be as efficient compared to the values calculated in Section 3.1.1.2.
Resistor values and gate driver capacitors used for the MPPT can be selected from the array of resistors and capacitors inside the lab, thus does not need to be addressed in the BOM. Approximate values can be used as the error can be negligible.

### 3.2. Schematic


Figure 3.2: Schematic of the MPPT system

Using the incorrect values provided in the BOM, the MPPT schematic in Figure 3.2 was created using Altium Designer which encompasses 2 opAmps for the sensors along with a current shunt resistor, gate driver for the MCU generated pulse, 1 x 2 pin terminal, 1 x 4 pin terminal, a smoothing capacitor and a buck-boost converter. This schematic will then be turned into a PCB using Altium Designer so that the MPPT can be wired up to the PV system, the MCU and the load resistors / simulated BMS. The incorrect values can later be altered as the schematic is arranged in a way to allow for easy replacement of components.

### 3.3. Board layout


Figure 3.3: PCB designed in Altium Designer

As observed in Figure 3.3, the PCB was designed in Altium Designer which will later be outsourced to create the final PCB. This PCB was arranged so that connections of different components would not interfere with one another.

### 3.4. Algorithm Design


Figure 3.4: InC MPPT algorithm

As observed in Figure 3.4 the InC algorithm will be implemented on the MCU so that MPP can be achieved when power is applied on the load resistor. The voltage and current sensor will act as inputs and thus, follow the given flow diagram. Using the MCU to generate a PWM output, operating voltage manipulation can be achieved by altering the gate driver’s PWM, which alters the switching frequency of the buck-boost converter’s MOSFET, consequently achieving MPP.

### 4. Implementation

### 4.1. Hardware implementation


Figure 4.1: Failed hardware implementation of the MPPT

Figure 3.2 schematic shows that the current sensor uses 1kΩ resistors R3 and R5, however, the hardware implementation in Figure 4.1 used a 10kΩ resistor to reduce the consumption of the sensor. The feedback and ground resistor increased by an order of magnitude in an attempt to match the desired gain calculated in Equation 3.1.1.1b. In addition, the smoothing capacitor was changed to 68μF since this was the largest available capacitor. Because of the lack of an exact resistor to match Equations 3.1.1.1a and 3.1.1.1b, there was deviation of values calculated for resistors. A slight deviation of this magnitude is negligible so long as the output voltage does not exceed 5V; however, calibration may be necessary for the sensors.
In Figure 4.1, the MPPT PCB circuit without the MCU and PV system is shown along with the schematic in Figure 3.2 and Altium Designer PCB in Figure 3.3. Nonetheless, due to a missing line connection of this PCB design, the hardware implementation was discontinued to prevent potential hazards caused by faulty power electronics.

### 4.2. Software simulation


Figure 4.2: Simulated MPPT system with PV and load resistor

The MPPT simulator is highlighted in Figure 4.2.1 due to a hardware failure caused by a misconstruction of the MPPT PCB in Section 3.2. However, this simulation will provide sufficient parameters for determining the feasibility of an MPPT using the InC algorithm. In a subsection, the uncontrolled system is displayed, while the controlled system is shown outside the subsection.
The simulated voltage and current sensor can be represented by the voltage and current measurement block, the gate driver can be represented by the PWM block, the MOSFET of the buck-boost converter can be represented by the MOSFET block and the 2 polycrystalline panels can be presented by the PV block. Furthermore, the buck-boost converter can be represented by the arrangement of diode, inductor, capacitor and finally, the BMS/load resistor can be represented by the resistor block. As shown in Figure 3.2, the simulation is designed in a similar manner. Additionally
The buck-boost converter capacitor and inductor values of the simulated MPPT deviated from the BOM component values to compensate for the misculations that occur prior to this report mentioned in Section 3.1.2. Consequently, the simulated buck-boost capacitor and inductor will follow the values of Equation 3.1.1.2, thus C = 4.84μF and L = 1.5mH.

### 4.2.1. Algorithm


Figure 4.1: Implemented InC MPPT algorithm as shown in Figure 3.4

Figure 4.1 highlights the InC algorithm designed in Section 3.4 that was coded in the Matlab simulation of the MPPT. The InC algorithm processes the voltage and current detected by the simulated sensors (which intended to work as the sensors designed in Section 3.1.1) to output a PWM for the simulated gate driver. Although changing the duty cycle of a MCU’s output to suit a specific load resistor value may result in greater efficiency, it wouldn’t be practical in a real world scenario as consumers will generally not be able take apart an MPPT. Therefore, the duty cycle was initialised at 0.7259 as calculated in Equation 3.1.1.2.

### 5. Evaluation

To compare the efficacy of the MPPT in different weather conditions it may be advised to create 2
step input from 0 to 1000W/m and | to gauge the it’s performance under high and low

2
0 to 400W/m

2
solar irradiance. These parameters will be conducted on the 1Ω, 10Ω, 100Ω load resistors to assess the feasibility of a controlled system versus an uncontrolled system. Figures 5.1-3 show the uncontrolled system in pink and the controlled system in blue.
5.1. 1Ω Resistor


Figure 5.1: 0 to 400W/m (top) and | (bottom)

2
0 to 1000W/m
| 2
Step input | Uncontrolled Steady state | Controlled Steady state
2 0 to 400W/m | 0.057 W | N/A
2 0 to 1000W/m | 0.36 W | N/A

Table 5.1: 1Ω resistor MPPT results

The results from the simulation as shown in Figure 5.1 illustrates that an MPPT (controlled system) may not be feasible for a load resistor of 1Ω as it converges instead of reaching a steady state compared to an uncontrolled system which achieves steady state in both step inputs as shown in Table 5.1. This may be a result of an unchanged duty cycle as it doesn’t follow the same duty cycle suggested in Equation 3.1.1.2 or an error in the Simulink model. Additionally, the algorithm could have some errors. These findings suggest that if a 1Ω was the impedance of a BMS, it may be recommended to use an uncontrolled system.
5.2. 10Ω Resistor


Figure 5.2: 0 to 400W/m (top) and | (bottom)

2
0 to 1000W/m
| 2
Step input | Uncontrolled Steady state | Controlled Steady state
2 0 to 400W/m | 0.57 W | N/A
2 0 to 1000W/m | 3.584 W | N/A

Table 5.2: 10Ω resistor MPPT results

The results from the simulation as shown in Figure 5.2 illustrates that an MPPT (controlled system) may not be feasible for a load resistor of 10Ω as it converges instead of reaching a steady state compared to an uncontrolled system which achieves steady state in both step inputs as shown in Table 5.2.
It can also be shown that a 10Ω resistor underperforms compared to a 1Ω resistive load. This may be a result of an unchanged duty cycle as it doesn’t follow the same duty cycle suggested in

Equation 3.1.1.2 or an error in the Simulink model. Additionally, the algorithm may have some errors. These findings suggest that if a 10Ω was the impedance of a BMS, it may be recommended to use an uncontrolled system.
5.3. 100Ω Resistor


Figure 5.3: 0 to 400W/m (top) and | (bottom)

2
0 to 1000W/m
| 2
Step input | Uncontrolled Steady state | Controlled Steady state
2 0 to 400W/m | 5.7 W | 8.5 W
2 0 to 1000W/m | 17 W | 21 W

Table 5.3: 100Ω resistor MPPT results

The results from the simulation as shown in Figure 5.3 illustrates that an MPPT (controlled system) is feasible with a resistive load of 100Ω so long at there is 1000W/m of solar irradiance available.

2
Compared to the 0 to 400W/m step function, the | achieves steady state at a faster

2
0 to 1000W/m

2
rate. Additionally, the 0 to 1000W/m step input has shown to achieve a steady state of 21 W with an

2
oscillation of 0.7%. Whereas the step input of 0 to 400W/m achieved a steady state of 8.5 W with

2
0.03% oscillation.
The 100Ω provides the best MPPT outcome when compared to other load resistors. Therefore, in order for an MPPT to function effectively in this simulation, the load resistor must be 100Ω. It is possible to use an MPPT if the right parameters are provided, such as a 100Ω impedance

BMS. Even so, the rate at which steady state is achieved could raise questions about the MPPT's overall performance due to the constantly changing weather.

### 6. Conclusion

In retrospect, the hardware implementation of MPPT could benefit from additional safety features, such as a diode connected in series with the PV system, to allow current to follow the desired direction, thereby preventing polarity hazards. Future MPPT versions might include safety measures such as an LED light to indicate the wiring of the system is not faulty. Additionally, more cost-effective microcontrollers might be used as the InC algorithm is computationally inexpensive. According to section 5, the feasibility of MPPTs can vary with the load impedance and solar irradiance within a simulated renewable energy system. Depending on the load impedance and/or the solar irradiance, an MPPT may underperform. Furthermore, the rate at which the controlled system achieves a steady state may also vary depending on the availability of solar irradiance. Although the simulation deviated from what is expected from an MPPT, the converging characteristics shown in the controlled output (1Ω, 10Ω, 100Ω [0 to 400W/m ) may indicate that the

2
]
controlled system does eventually reach its MPP. A steady state can be reached within a 10 second time frame as shown in Figure 5.3 suggests that the rate at which the system achieves steady state after convergence may be negligible in a practical sense.

Reference

[1] “Maximum Power Point Tracking (MPPT) charge controller working principle,” Electrical Academia. [Online]. Available: https://electricalacademia.com/renewable-energy/maximum-power-point-tracking-mppt-charge-controller-working-principle/. [Accessed: 15-Jun-2022].
[2] I. W. Christopher and R. Ramesh, “Comparative study of p&o and inc mppt algorithms,” American Journal of Engineering Research (AJER), vol. 2, no. 12, pp. 402–408, 2013. 12
[3] F. Kano, Y. Kasai, H. Kimura, K. Sagawa, J. Haruna and H. Funato, "Buck-Boost Type MPPT Circuit Suitable for Photovoltaic Generation of Vehicle Installation," 2018 International Power Electronics Conference (IPEC-Niigata 2018 -ECCE Asia), 2018, pp. 2036-2041, doi: 10.23919/IPEC.2018.8507955.
[4] Admin, “Buck-boost converter in CircuiTikZ,” TikZBlog, 10-Feb-2021. [Online]. Available: https://latexdraw.com/buck-boost-converter-in-circuitikz/. [Accessed: 15-Jun-2022].
[5] Admin, “Buck-boost converter in CircuiTikZ,” TikZBlog, 10-Feb-2021. [Online]. Available: https://latexdraw.com/buck-boost-converter-in-circuitikz/. [Accessed: 15-Jun-2022].

[6]“Opamp output voltage in negative feedback,” Electrical Engineering Stack Exchange, 02-Dec-2020. [Online]. Available: https://electronics.stackexchange.com/questions/535215/opamp-output-voltage-in-negative-feedback. [Accessed: 15-Jun-2022].

[7 ] “File:op-amp differential Amplifier.svg,” Wikipedia, 26-Jan-2009. [Online]. Available: https://en.wikipedia.org/wiki/File:Op-Amp_Differential_Amplifier.svg. [Accessed: 15-Jun-2022].
